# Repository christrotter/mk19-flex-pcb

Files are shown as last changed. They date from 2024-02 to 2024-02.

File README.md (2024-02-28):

# mk19-flex-pcb
All credit to: [Cyboard](https://github.com/Cyboard-DigitalTailor/cyboard-public)

Custom flex pcb/cable/thing for the mk19 pcb rev2, an extended version of the Cyboard factory cable.

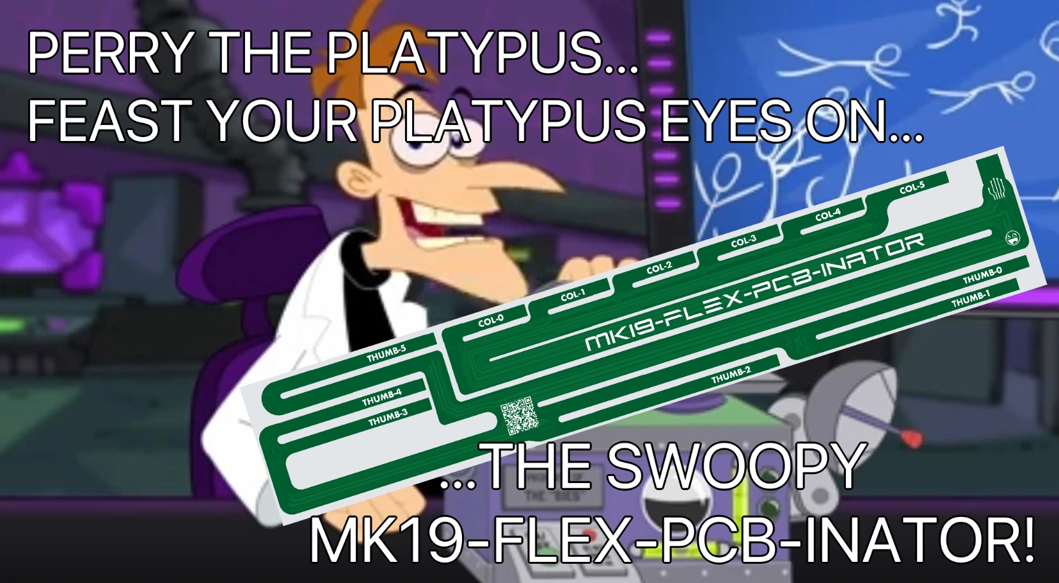
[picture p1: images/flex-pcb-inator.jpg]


# ordering notes
## creating gerbers.zip
Follow their docs: 
- https://jlcpcb.com/help/article/495-easyeda-flex-pcb-design-user-guide
- https://jlcpcb.com/help/article/362-how-to-generate-gerber-and-drill-files-in-kicad-7

Ensure you include the User_Drawings layer.

**Example gerber file contents:**
```
mk19-flex-pcb-B_Cu.gbl
mk19-flex-pcb-B_Mask.gbs
mk19-flex-pcb-B_Paste.gbp
mk19-flex-pcb-B_Silkscreen.gbo
mk19-flex-pcb-Edge_Cuts.gm1
mk19-flex-pcb-F_Cu.gtl
mk19-flex-pcb-F_Mask.gts
mk19-flex-pcb-F_Paste.gtp
mk19-flex-pcb-F_Silkscreen.gto
mk19-flex-pcb-NPTH-drl_map.gbr
mk19-flex-pcb-NPTH.drl
mk19-flex-pcb-PTH-drl_map.gbr
mk19-flex-pcb-PTH.drl
mk19-flex-pcb-User_Drawings.gbr
mk19-flex-pcb-gerbers.zip
mk19-flex-pcb-job.gbrjob
```

## submitting the order
- whatever quantity you want
- 0.12 pcb thickness
- polyimide stiffener; 0.1mm
- 0.2mm gold fingers
- colour: white

1. On the initial order page.  The very first page where you add the gerbers.zip file.
2. Veerrrrrrry bottom: 'add pcb remark'
3. Ensure you add a comment in here that says: 
```
Please see 'mk19-flex-pcb-User_Drawings.gbr' for stiffener locations and remarks - there should be only a small amount of stiffener required. I understand this requires extra charges for the small slots - that's fine.
```

# overview

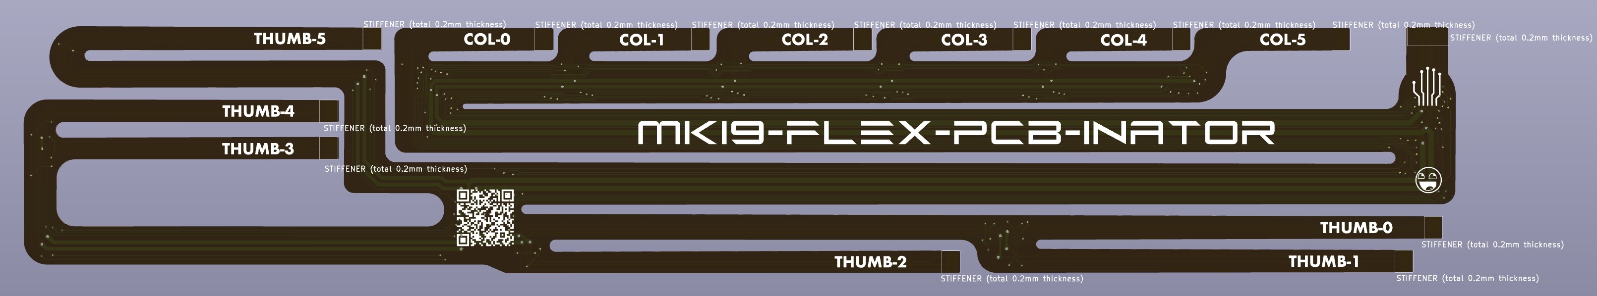
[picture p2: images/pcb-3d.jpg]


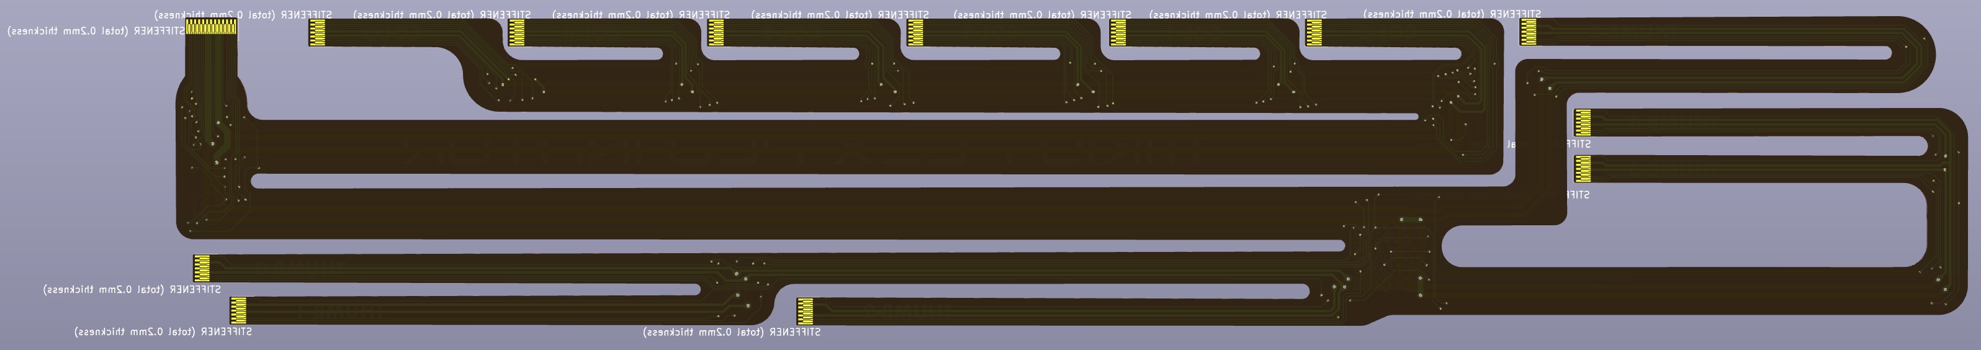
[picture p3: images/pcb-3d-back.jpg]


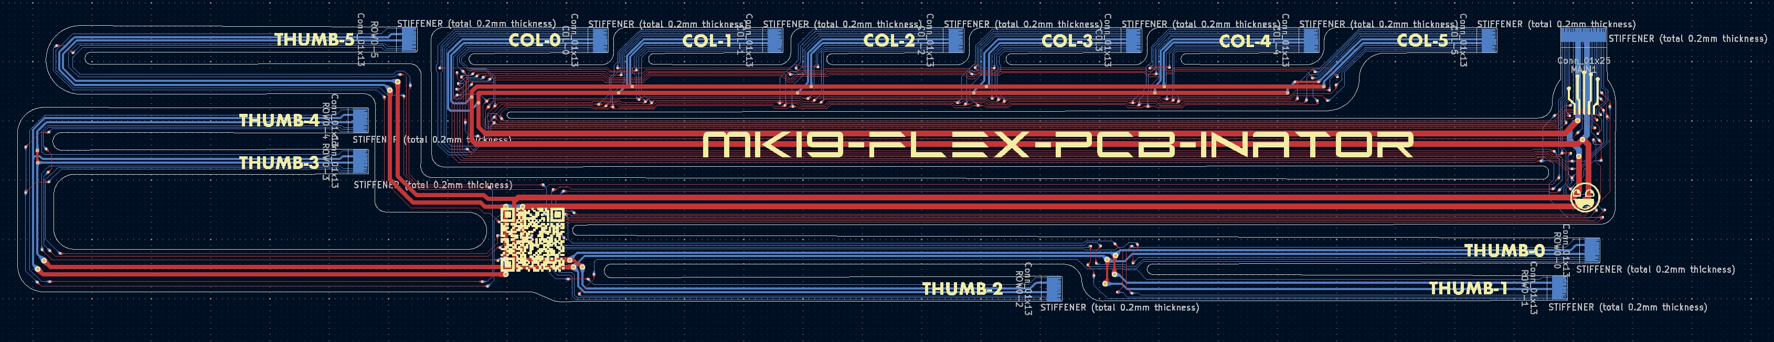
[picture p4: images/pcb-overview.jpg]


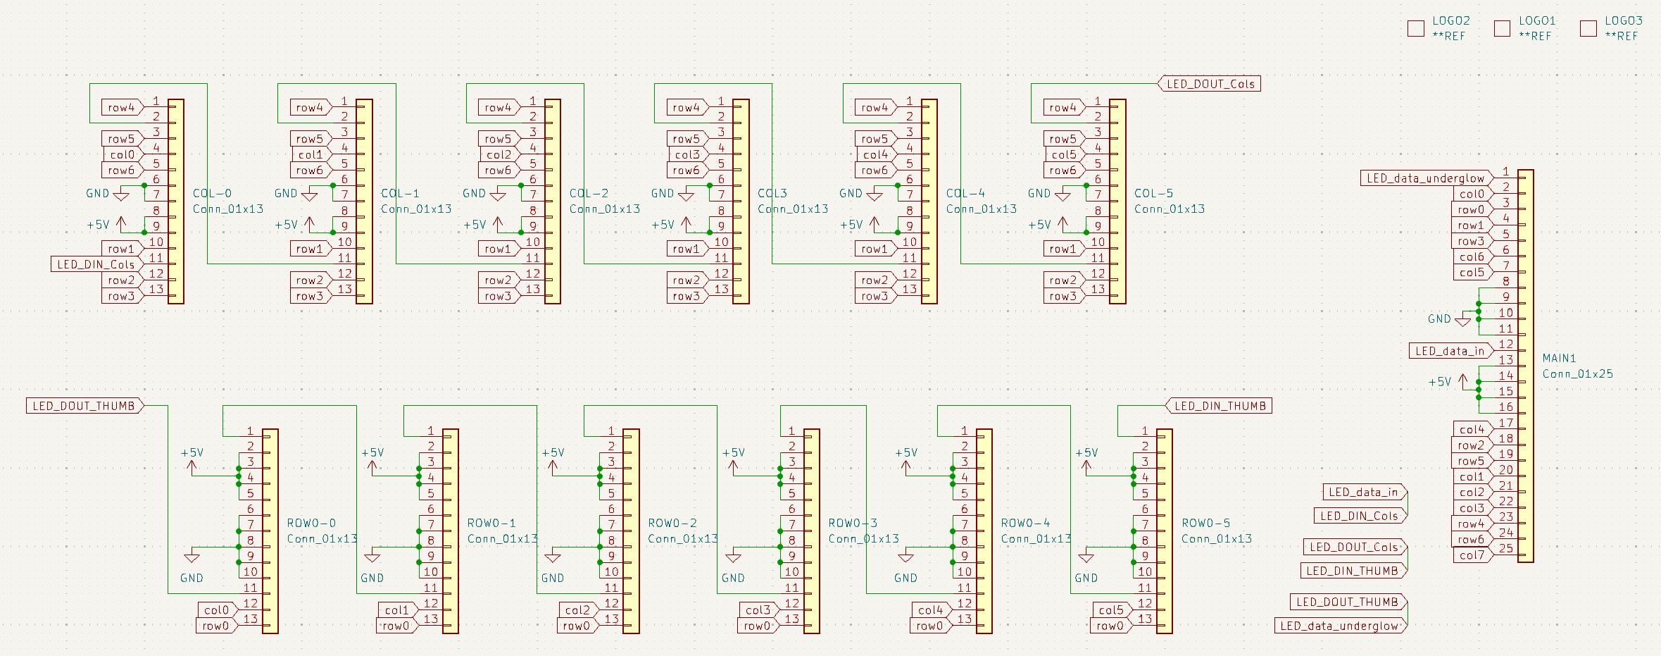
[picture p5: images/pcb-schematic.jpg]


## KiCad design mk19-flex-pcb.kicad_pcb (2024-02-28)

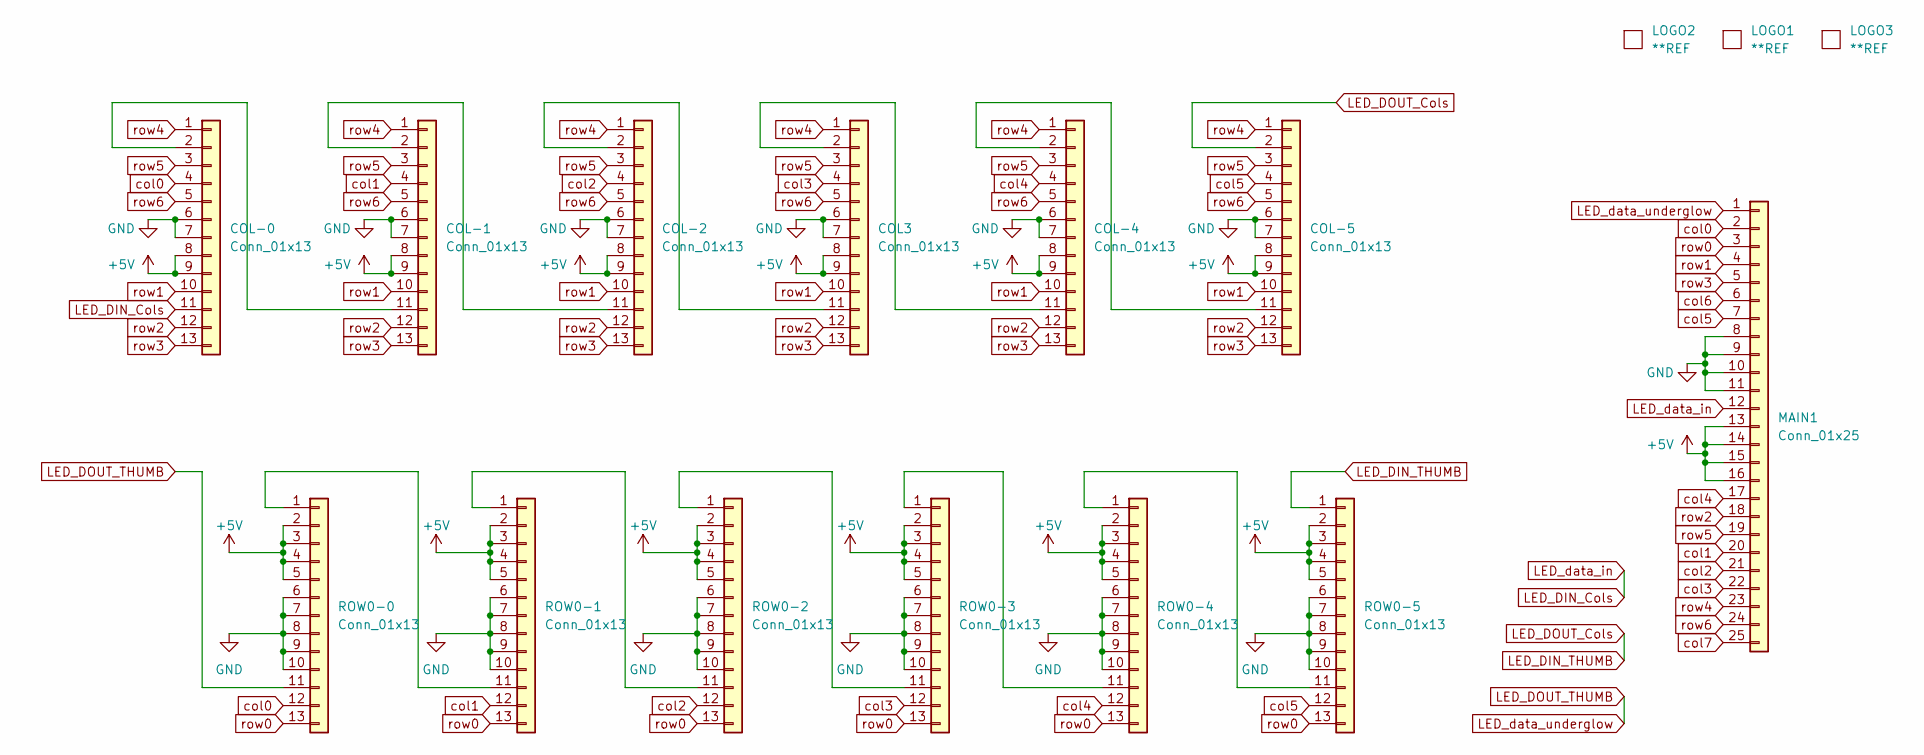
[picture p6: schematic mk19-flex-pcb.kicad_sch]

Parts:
COL3: Conn_01x13; FFC Termination 13x0.3 ECT818001568
COL-0, COL-1, COL-2, COL-4, COL-5: Conn_01x13; FFC Termination 13x0.3 ECT818001568
LOGO1: **REF; awesome-logo
LOGO2: **REF; cyboard-logo-10mm
LOGO3: **REF; mk19-flex-pcb-qr-12mm
MAIN1: Conn_01x25; FFC Termination 25x0.3 ECT818001569
ROW0-0, ROW0-1, ROW0-2, ROW0-3, ROW0-4, ROW0-5: Conn_01x13; FFC Termination 13x0.3 ECT818001568

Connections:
+5V: COL3.8, COL3.9, COL-0.8, COL-0.9, COL-1.8, COL-1.9, COL-2.8, COL-2.9, COL-4.8, COL-4.9, COL-5.8, COL-5.9, MAIN1.13, MAIN1.14, MAIN1.15, MAIN1.16, ROW0-0.2, ROW0-0.3, ROW0-0.4, ROW0-0.5, ROW0-1.2, ROW0-1.3, ROW0-1.4, ROW0-1.5, ROW0-2.2, ROW0-2.3, ROW0-2.4, ROW0-2.5, ROW0-3.2, ROW0-3.3, ROW0-3.4, ROW0-3.5, ROW0-4.2, ROW0-4.3, ROW0-4.4, ROW0-4.5, ROW0-5.2, ROW0-5.3, ROW0-5.4, ROW0-5.5
GND: COL3.6, COL3.7, COL-0.6, COL-0.7, COL-1.6, COL-1.7, COL-2.6, COL-2.7, COL-4.6, COL-4.7, COL-5.6, COL-5.7, MAIN1.8, MAIN1.9, MAIN1.10, MAIN1.11, ROW0-0.6, ROW0-0.7, ROW0-0.8, ROW0-0.9, ROW0-0.10, ROW0-1.6, ROW0-1.7, ROW0-1.8, ROW0-1.9, ROW0-1.10, ROW0-2.6, ROW0-2.7, ROW0-2.8, ROW0-2.9, ROW0-2.10, ROW0-3.6, ROW0-3.7, ROW0-3.8, ROW0-3.9, ROW0-3.10, ROW0-4.6, ROW0-4.7, ROW0-4.8, ROW0-4.9, ROW0-4.10, ROW0-5.6, ROW0-5.7, ROW0-5.8, ROW0-5.9, ROW0-5.10
LED_DIN_Cols: COL-0.11, MAIN1.12
LED_DIN_THUMB: COL-5.2, ROW0-5.1
LED_DOUT_THUMB: MAIN1.1, ROW0-0.11
unnamed: COL-0.2, COL-1.11
unnamed: COL-1.2, COL-2.11
unnamed: COL3.11, COL-2.2
unnamed: COL-4.2, COL-5.11
unnamed: COL3.2, COL-4.11
unnamed: ROW0-0.1, ROW0-1.11
unnamed: ROW0-1.1, ROW0-2.11
unnamed: ROW0-2.1, ROW0-3.11
unnamed: ROW0-3.1, ROW0-4.11
unnamed: ROW0-4.1, ROW0-5.11
col0: COL-0.4, MAIN1.2, ROW0-0.12
col1: COL-1.4, MAIN1.20, ROW0-1.12
col2: COL-2.4, MAIN1.21, ROW0-2.12
col3: COL3.4, MAIN1.22, ROW0-3.12
col4: COL-4.4, MAIN1.17, ROW0-4.12
col5: COL-5.4, MAIN1.7, ROW0-5.12
col6: MAIN1.6
col7: MAIN1.25
row0: MAIN1.3, ROW0-0.13, ROW0-1.13, ROW0-2.13, ROW0-3.13, ROW0-4.13, ROW0-5.13
row1: COL3.10, COL-0.10, COL-1.10, COL-2.10, COL-4.10, COL-5.10, MAIN1.4
row2: COL3.12, COL-0.12, COL-1.12, COL-2.12, COL-4.12, COL-5.12, MAIN1.18
row3: COL3.13, COL-0.13, COL-1.13, COL-2.13, COL-4.13, COL-5.13, MAIN1.5
row4: COL3.1, COL-0.1, COL-1.1, COL-2.1, COL-4.1, COL-5.1, MAIN1.23
row5: COL3.3, COL-0.3, COL-1.3, COL-2.3, COL-4.3, COL-5.3, MAIN1.19
row6: COL3.5, COL-0.5, COL-1.5, COL-2.5, COL-4.5, COL-5.5, MAIN1.24

Board: 2 copper layers, 16 parts (0 on the bottom side), 28 nets.

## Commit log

2024-02-25 working flex shape, needs routing
    [mk19-flex-pcb.kicad_pcb, mk19-flex-pcb.kicad_sch]
2024-02-25 ready for review
    [mk19-flex-pcb.kicad_pcb]
2024-02-25 moving stiffener labels
    [mk19-flex-pcb.kicad_pcb]
2024-02-26 adding teardrops, fixing a few odds and ends
    [mk19-flex-pcb.kicad_pcb]
2024-02-26 fixing up the teardrops and spacing out vias for better tolerances
    [mk19-flex-pcb.kicad_pcb]
2024-02-26 fixing up the tab edge spacing of traces
    [mk19-flex-pcb.kicad_pcb]
2024-02-26 final changes before production
    [mk19-flex-pcb.kicad_pcb, mk19-flex-pcb.kicad_sch]
2024-02-26 organizing the schematic
    [mk19-flex-pcb.kicad_sch]
